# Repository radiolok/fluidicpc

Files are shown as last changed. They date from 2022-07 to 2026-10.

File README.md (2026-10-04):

# FluidicPC

Вычислительные устройства на элементах струйной логики: от моделей отдельных элементов и расчёта течения до синтеза схем и разводки плат.

## Проекты и инструменты

| Папка | Что внутри |
|---|---|
| [`calculator/`](calculator) | **Струйный калькулятор** — арт-объект на 852 элементах: распознаёт символ с матрицы трубочек 5 × 7, считает и показывает результат на семисегментных индикаторах. Модель, структурный и высокоуровневый Verilog, расчёты питания и конструктива |
| [`adder/`](adder) | 4-разрядный сумматор: Verilog, синтез в библиотеку струйных элементов (`fluidic.lib`), тестбенч |
| [`elements/`](elements) | 3D-модели элементов «Волга» (СТ41, СТ42, СТ43, СТ55, СТ56, СТ59, СТ60, СТ63 и др.) во FreeCAD |
| [`bench/`](bench) | расчёт течения в элементе СТ41 в OpenFOAM: подготовка сетки и запуск на кластере |
| [`sch/`](sch) | схемы и плата сумматора в KiCad |
| [`verilog2netlist/`](verilog2netlist) | конвертер синтезированного Verilog в netlist и плату KiCad |

## Струйный калькулятор

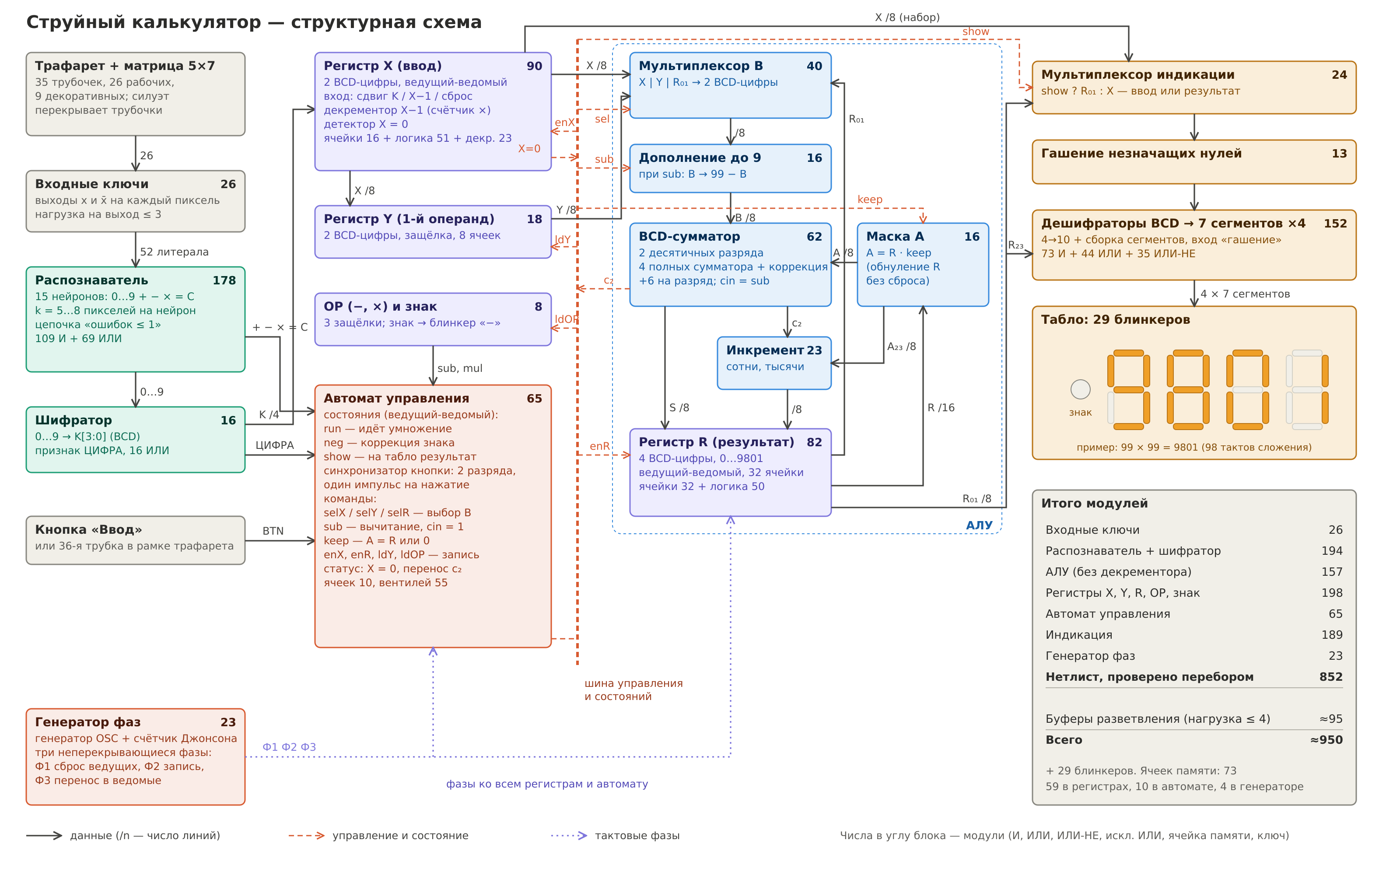
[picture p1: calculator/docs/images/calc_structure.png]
Структурная схема калькулятора


Ввод — трафарет на матрице трубочек и кнопка «Ввод». Операнды от 0 до 99, операции `+ − ×`. Схема разложена на 8 даёв по 150 элементов. Даи попарно собраны в 4 вертикальных блока, блоки стоят на объединительной плите с буферной полостью питания.

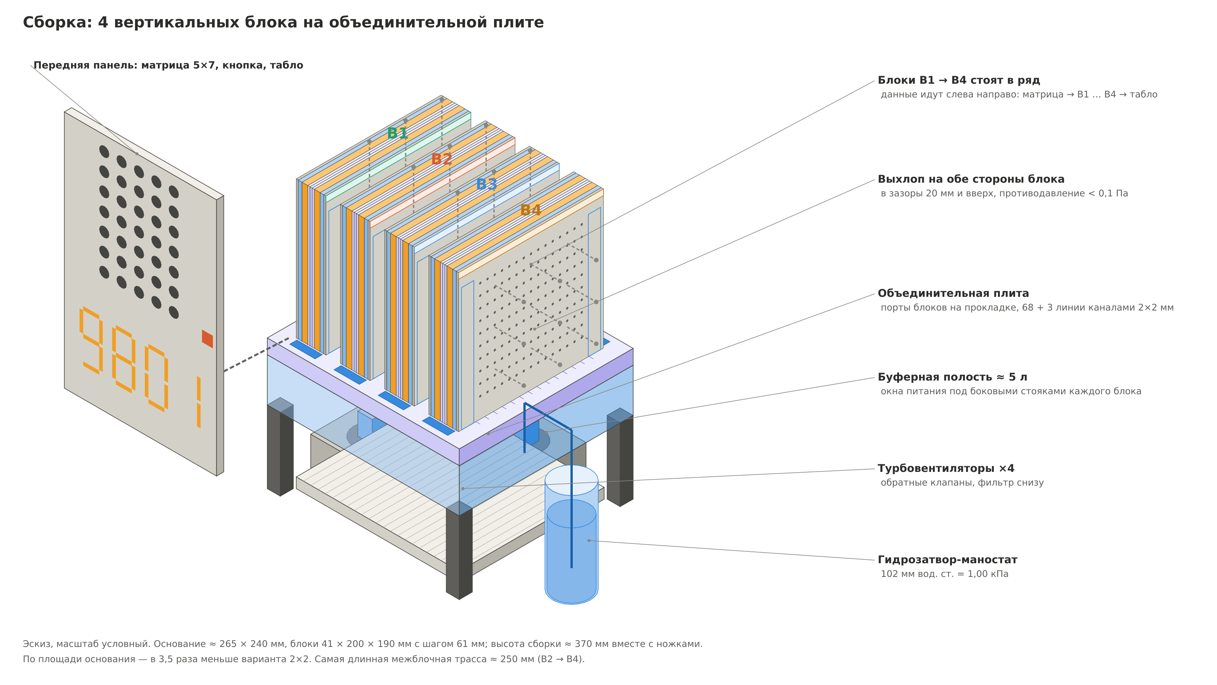
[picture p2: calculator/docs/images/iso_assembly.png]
Сборка: 4 блока на объединительной плите


Подробнее — в [`calculator/README.md`](calculator/README.md).

## Лицензия

[LICENSE](LICENSE)

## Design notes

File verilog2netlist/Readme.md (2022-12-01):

# verilog to netlist
Конвертирует verilog в netlist из которого можно сделать pcb в KiCad 6.

## Установка
Установка зависимостей
```:bash
pip install pipenv
pipenv shell
pipenv install
```
Зависимости: Python 3.8 или выше

## Использование

В папке `FA` содержится пример пустого проекта со всеми библиотеками добавленными в проект. Эти библиотеки используются при создании netlist.

`FA_result` уже готовый что будет после работы скрипты. 

Конфигурационный файл config.py 

Для каждого модуля создаются свои правила по ключу в словаре. Каждый объект правил содержит ключи:
- `verilog_type` — имя в элемента в верилог файле обязательно должны быть элементы для `input` и для `output` остальные например `NOT `опциональны если правила нет элемент в netlist не добавляется
- `kicad_schematic_lib` — имя кикад библиотеки схем так как его назвали при экспортировании в диалоге проекта Kicad 6 `Preferences → Manage Symbol Libraries... → Project Specific Libraries`
- `kicad_scheamtic_element` — Имя элемента как назван в библиотеке схем экспортированной выше
`kicad_footprint` — футпринт элемента в формате `{имя библиотеки}:{имя элемента}` в диалоге проекта Kicad 6 `Preferences → Manage Footprint Libraries... → Project Specific Libraries`
- `pins` — правила замены имен пинов из верилог файла в пины элемента Kicad. Пины в кикад могут быть названия как по `name` так и по `number`. В shematic элемента у пина могут быть указаны как `name` так и `number` оба параметра могут быть текстом. У footprint у пинов есть только `number`

Пример:

```
...
"FA": [{
    "verilog_type": "input",
    "kicad_schematic_lib": "FA",
    "kicad_schematic_element": "HOLE",
    "kicad_footprint": "FA:HOLE",
    "pins": {},
},
    {
    "verilog_type": "output",
        "kicad_schematic_lib": "FA",
        "kicad_schematic_element": "HOLE",
        "kicad_footprint": "FA:HOLE",
        "pins": {},
},{
    "verilog_type": "NOR",
        "kicad_schematic_lib": "FA",
        "kicad_schematic_element": "NOR",
        "kicad_footprint": "FA:NOR",
        "pins": {
            ".A": {
                "number": "4"
            },
            ".B": {
                "number": "5"
            },
            ".Y": {
                "number": "7"
            }},
},]
...
```
Элементы верилог файла
```
...
  input ci;
...
  output co;
...
  NOR _12_ (
    .A(_05_),
    .B(_06_),
    .Y(_08_)
  );
...
```

## Командная строка 
```
> python main.py
```

```
> python main.py --help
usage: main.py [-h] [-i [INPUT]] [-l [LIB]]
               [-o [OUTPUT]]

Convert verilog file to netlist

optional arguments:
  -h, --help            show this help
                        message and exit
  -i [INPUT], --input [INPUT]
                        Input verilog file.
                        default is verilog_in
                        puts/adder_synth.v
  -l [LIB], --lib [LIB]
                        Add kicad library
                        path. Multiple path
                        is allowed. default
                        is FA
  -o [OUTPUT], --output [OUTPUT]
                        Output folder.
                        default is
                        netlists_outputs
```
Необязательные параметры
- `-i` — имя входного верилог файла
- `-l` — путь до библиотеки Kicad 6 можно использовать не только проектную, но и глобальную библиотеку. Пути можно найти в документации по Kicad 6, можно добавить несколько путей для библиотек искать будет во всех.
- `-o` — имя папки куда попадут netlist от каждого модуля. Имя файла будет имя модуля с расширением `*.net`

## Что делать с netlist

Можно создать новый проект добавиь в него все библиотеки из исходного проект `*.kicad_sym`, папки `*.pretty` с файлами с расширением `*.kicad_mod`

В файле проект открыть `PCB editor`

Нажать `File → Import → Netlist` в Диалоге нажать `Update PCB` закрыть `Close`

К курсору прилипнут все элементы из netlist расположить их в удобном месте. Все соединенные пины должны быть соединены прямой линией

Расставить как будет удобно.

После этого можно будет сделать автотрассировку

## Автотрассировка

Скачать и установть LayoutEditor https://layouteditor.com/download если нет java то её тоже установить https://www.java.com/

Нажать в Kicad PCD Editor `File → Export → Spectra DSN...` сохранить.

В установленном приложении LayoutEditor найти файл `freeRouting.jar` в Windows в папке программ `LayoutEditor\bin\freeRouting.jar`

Запустить в диалоге выбрать `*.dsn` файл созданные ранее. 

В открывшемся приложении выборать `Routing → Autorouting` Когда процесс завершится нажать `File → Export → Export Spectra Session File` Файл сохранится в той же папке и с тем же названием только расширение будет `*.ses` на вопрос нажать `Yes`

В `PCB Editor` из Kicad открыв тот же файл куда импортировался netlist нажать `File → Import → Spectra Session...` выбрать новый `*.ses` файл. Все элементы соединятся проводниками.

Теперь можно выбрать один или несколько выходов и нажать апостроф "`" пути соединений будут подсвечены.

Удалить путь чтобы разметить заново `Edit → Global Deletations...` выбрать `Tracks & vias` → `OK` → `Yes`. Теперь можно переставить элементы и разметить заново.

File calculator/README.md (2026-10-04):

# Струйный калькулятор

Вычислительное устройство на элементах струйной логики (прилипание ламинарной струи к стенке), задуманное как арт-объект. Символ задаётся трафаретом: силуэт перекрывает часть трубочек матрицы 5 × 7. Машина распознаёт символ, считает в двоично-десятичном коде и показывает результат на четырёх семисегментных индикаторах из блинкеров. Умножение выполняется повторным сложением по одному такту, поэтому сумма на табло растёт на глазах, как у арифмометра.

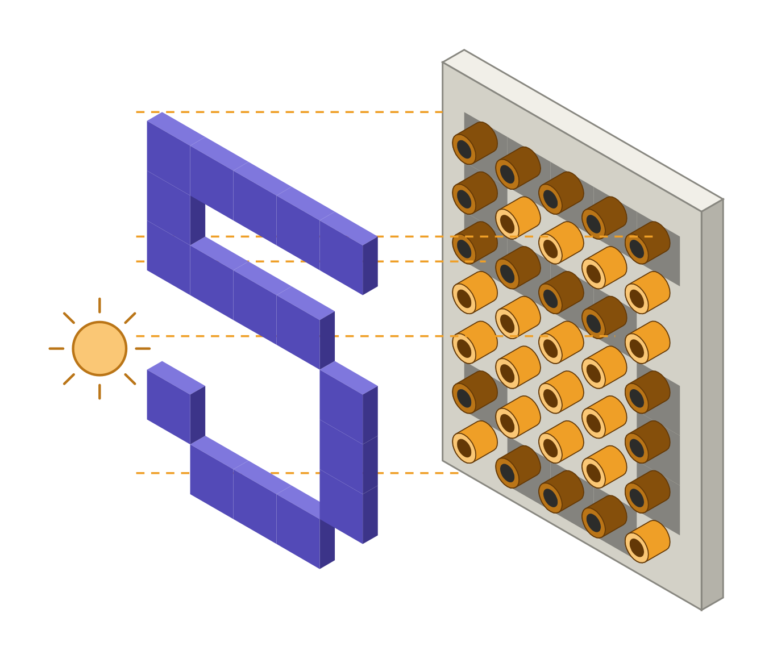
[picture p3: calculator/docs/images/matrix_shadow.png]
Трафарет отбрасывает тень на матрицу трубочек


| Параметр | Значение |
|---|---|
| Ввод | матрица 5 × 7 трубочек (26 рабочих) и кнопка «Ввод» |
| Символы | `0–9 + − × = C`; одна ошибка пикселя не мешает распознаванию |
| Операнды и результат | 0…99, результат −99…9801 |
| Вывод | 4 семисегментных индикатора и блинкер «−» (29 блинкеров) |
| Логика | 852 элемента: 2И, 2ИЛИ, 2ИЛИ-НЕ, НЕ, 2искл.ИЛИ, RS-ячейка, ключ, генератор |
| Конструктив | 8 даёв 15 × 10 мест → 4 вертикальных блока по 2 дая → объединительная плита |
| Питание | ≈ 1 кПа, ≈ 500 л/мин, Re сопла ≈ 1150 |
| Такт | 3 фазы, ≈ 3 Гц; 99 × 99 считается ≈ 35 с |

## Документация

| Раздел | Что внутри |
|---|---|
| [Архитектура](docs/architecture.md) | распознаватель, регистры, порядок работы, АЛУ, тактирование, подсчёт элементов, быстродействие, допущения |
| [Конструктив](docs/construction.md) | место элемента, дай, вертикальный блок, разбиение по даям и блокам, объединительная плита |
| [Питание](docs/power.md) | режим сопла, расход, источник, полости, стояки, выхлоп, бюджет давления |

Структурная схема калькулятора

## Структура папки

| Папка | Содержимое |
|---|---|
| [`model/`](model) | эталонная модель на Python: вентильный нетлист, симулятор, тесты, генераторы Verilog. Источник правды для всего остального |
| [`netlist/`](netlist) | структурный Verilog для разводки: 8 даёв, 4 блока, верхний уровень, библиотека ячеек, тестбенчи. **Генерируется** из `model/`, руками не править |
| [`rtl/`](rtl) | высокоуровневая (поведенческая) модель на Verilog и её тестбенч |
| [`calc/`](calc) | отдельные расчёты: подбор весов распознавателя, пневматика, разбиение по даям |
| [`docs/`](docs) | описание проекта; картинки в `docs/images/`, скрипты, которые их рисуют, — в `docs/src/` |
| [`ci/`](ci) | обвязка шагов CI |

## Две версии на Verilog

**Структурный нетлист** (`netlist/`) — то, что идёт в разводку. Каждый экземпляр ячейки — один физический элемент на плате. Иерархия повторяет конструктив: модуль дая, модуль блока из двух даёв, верхний уровень с линиями объединительной платы.

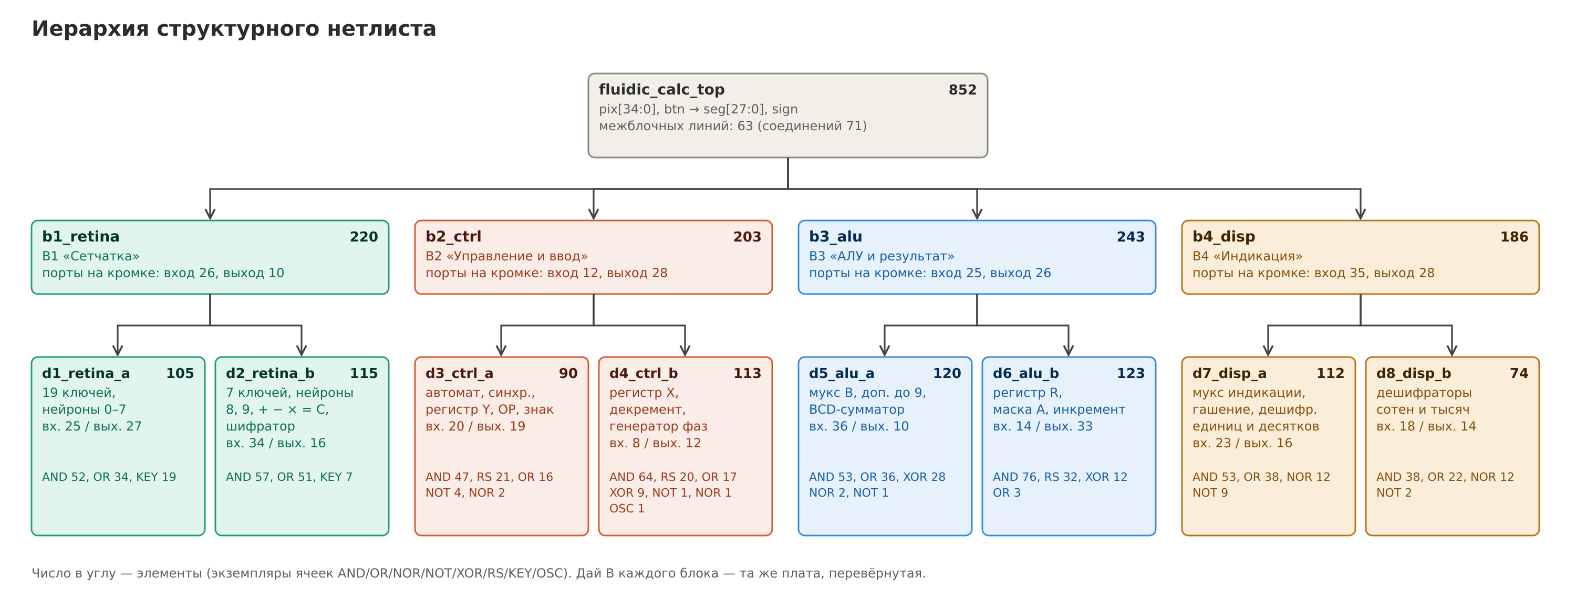
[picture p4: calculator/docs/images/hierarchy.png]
Иерархия структурного нетлиста


| Порт верхнего уровня | Назначение |
|---|---|
| `pix[34:0]` | трубочки матрицы, `pix[r*5 + c]`: r = 0…6 строка сверху, c = 0…4 столбец слева; 1 — трубочка закрыта |
| `btn` | кнопка «Ввод» |
| `seg[27:0]` | сегменты, `seg[7*k + j]`: k = 0 единицы … 3 тысячи; j = 0…6 сегменты a…g |
| `sign` | блинкер «−» |

Библиотека ячеек [`netlist/cells/fluidic_cells.v`](netlist/cells/fluidic_cells.v) с макросом `SYNTHESIS` превращает элементы в чёрные ящики, и иерархия даёв и блоков сохраняется при синтезе. Без макроса это поведенческие модели с задержкой элемента. Для yosys есть Liberty-описание [`netlist/cells/fluidic_calc.lib`](netlist/cells/fluidic_calc.lib).

**Высокоуровневая модель** ([`rtl/fluidic_calc_rtl.v`](rtl/fluidic_calc_rtl.v)) описывает те же регистры, события и уравнения арифметикой, без вентилей. Один фронт `clk` в ней соответствует одному такту машины. Она служит эталоном: тестбенч `netlist/tb_cosim.v` гоняет её одновременно с нетлистом и сверяет табло после каждого такта.

## Как проверить

Нужны `python3`, `iverilog` и `yosys`.

```sh
cd calculator
make model     # тесты Python-модели, структурная проверка нетлиста, сверка с RTL-зеркалом
make rtl       # тестбенч высокоуровневой модели
make netlist   # тестбенч структурного нетлиста с настоящим генератором фаз
make cosim     # нетлист и высокоуровневая модель такт в такт
make stat      # подсчёт элементов по даям и блокам
make regen     # перегенерировать нетлист и тестбенчи из модели
```

Все шаги запускает CI ([`.github/workflows/calculator.yml`](../.github/workflows/calculator.yml)). Он же проверяет, что закоммиченный нетлист совпадает с тем, что генерирует модель.

Полный перебор всех примеров `a op b` для a, b = 0…99 и `+ − ×` (30 000 штук) запускается отдельно, `python3 model/test_model.py full`, и идёт около часа. На текущей модели он проходит без ошибок.

## Перенос в KiCad

Нетлист даёв можно передать конвертеру [`verilog2netlist`](../verilog2netlist). В [`config.py`](../verilog2netlist/config.py) для даёв описаны правила только для NOR, OR и NOT: это элемент `FA:NOR`, ИЛИ снимается с вывода 6, ИЛИ-НЕ — с вывода 7. Для AND, XOR, RS-ячейки, ключа трубочки и генератора символов и футпринтов пока нет. Без правила элемент в netlist не попадает, поэтому правила нужно дописать, когда появятся библиотеки.

## Что ещё не сделано

- Буферы разветвления (≈ 95 при нагрузке на выход до 4) в нетлист не вставлены. Их удобнее добавлять при разводке, когда известны коэффициент разветвления и длины каналов.
- Сброса по включению нет: после подачи давления машина может минуту досчитывать случайное «умножение».
- Задержка элемента (1,5 мс), расход входа управления и допустимая нагрузка на выход — оценки. Их нужно измерить на реальных элементах. Что от них зависит — в разделе «Допущения» [архитектуры](docs/architecture.md#допущения).

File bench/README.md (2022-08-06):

## Openfoam preparations:

Install openfoam on Linux, or WSL [full instruction](https://develop.openfoam.com/Development/openfoam/-/wikis/precompiled/debian)

```bash
# Add the repository
curl https://dl.openfoam.com/add-debian-repo.sh | sudo bash

# Install preferred package. Eg,
sudo apt-get install openfoam2206-default

# Use the openfoam shell session. Eg,
openfoam2206
```

## ST41 openmpi benchmark

1. init env variables. Your openFoam installation might be differen

```bash

source /opt/OpenFoam_v2206/etc/bashrc
```

2. Prepare repo data

```bash
git clone https://github.com/radiolok/fluidicpc
cd fluidicpc/bench/st41_50u/meshCase
./Allmesh # run mesh preparation
cd ../case/
```

3. Prepare data for openMPI - set slots=CPUnum in your system

```bash
vim hostfile

127.0.0.1 slots=16
```

4. Set number of threads for current run

```bash
vim system/decomposeParDict

numberOfSubdomains  16;// <= change value in this line

```

5. Run simulation fo 50 iterations:

```bash
./Allrun
```

6. 

```bash
Time = 50

smoothSolver:  Solving for Ux, Initial residual = 0.016608048, Final residual = 0.0014078031, No Iterations 1
smoothSolver:  Solving for Uy, Initial residual = 0.0078743367, Final residual = 0.00052424984, No Iterations 1
smoothSolver:  Solving for Uz, Initial residual = 0.062228509, Final residual = 0.0056502976, No Iterations 1
GAMG:  Solving for p, Initial residual = 0.074983923, Final residual = 0.00061506252, No Iterations 3
GAMG:  Solving for p, Initial residual = 0.001528043, Final residual = 9.3656366e-06, No Iterations 12
GAMG:  Solving for p, Initial residual = 0.00021100964, Final residual = 1.4637146e-06, No Iterations 7
GAMG:  Solving for p, Initial residual = 3.1508808e-05, Final residual = 2.0603363e-07, No Iterations 7
GAMG:  Solving for p, Initial residual = 7.9916881e-06, Final residual = 6.9259462e-08, No Iterations 4
GAMG:  Solving for p, Initial residual = 2.0248575e-06, Final residual = 1.8799949e-08, No Iterations 4
time step continuity errors : sum local = 0.00031827139, global = 4.4203807e-06, cumulative = -0.0019786412
smoothSolver:  Solving for omega, Initial residual = 0.0088505726, Final residual = 0.00054960281, No Iterations 3
smoothSolver:  Solving for k, Initial residual = 0.034761292, Final residual = 0.0020115187, No Iterations 3
ExecutionTime = 699.06 s  ClockTime = 699 s <<<=== 699s for current test

End

Finalising parallel run

```

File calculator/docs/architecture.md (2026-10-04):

# Архитектура калькулятора

Структурная схема

## Ввод и распознавание

Символ задаётся трафаретом: силуэт перекрывает часть трубочек матрицы 5 × 7, и ключ каждой трубочки выдаёт прямой и инверсный сигнал. Распознаются 15 символов: `0–9 + − × = C`.

Каждый символ распознаёт свой нейрон с троичными весами: +1 — трубочка должна быть закрыта, −1 — открыта, 0 — нейрон на неё не смотрит. Нейрон срабатывает, если среди его пикселей не совпал с образцом **максимум один**. Веса подобраны перебором ([`calc/recognizer_weights.py`](../calc/recognizer_weights.py)):

- любой другой символ отличается от своего образца минимум в 3 пикселях из набора нейрона, поэтому одна ошибка пикселя не вызывает ни пропуска, ни ложного срабатывания;
- пустая и полностью закрытая матрица не будят ни один нейрон;
- используются 26 трубочек из 35, нагрузка на выход ключа не больше 3.

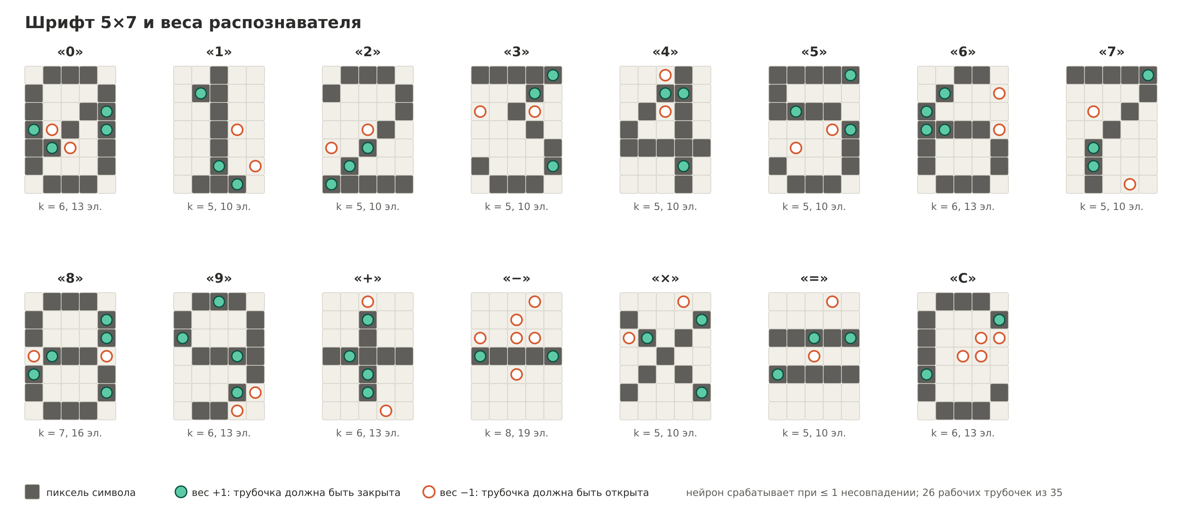
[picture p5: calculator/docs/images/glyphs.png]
Шрифт и веса


«Не более одного несовпадения» — это цепочка из двух рельсов на 2И/2ИЛИ, 3k − 5 элементов на нейрон из k пикселей:

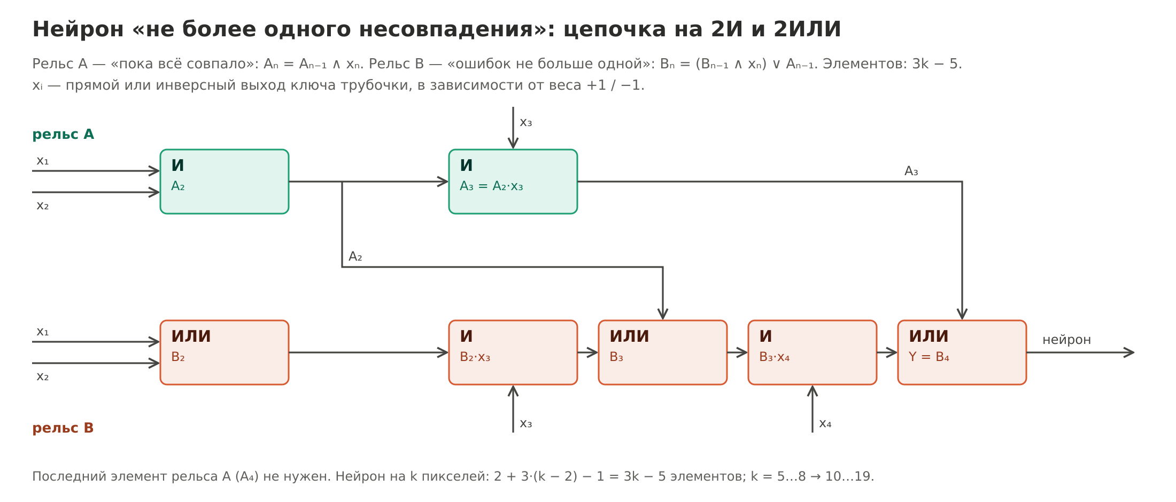
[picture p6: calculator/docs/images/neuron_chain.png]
Нейрон-цепочка


Шифратор собирает 10 выходов цифр в BCD-код K[3:0] и признак «цифра» — 16 элементов ИЛИ.

## Регистры и порядок работы

| Регистр | Разрядность | Тип | Назначение |
|---|---|---|---|
| X | 2 BCD-цифры | ведущий-ведомый | набираемое число; счётчик при умножении |
| Y | 2 BCD-цифры | защёлка | первый операнд |
| R | 4 BCD-цифры | ведущий-ведомый | результат, аккумулятор |
| OP | 2 бита | защёлка | отложенная операция: вычитание, умножение |
| знак | 1 бит | защёлка | блинкер «−» |
| run, neg, show | 3 бита | ведущий-ведомый | состояния автомата |
| синхронизатор | 2 бита | ведущий-ведомый | один импульс на нажатие кнопки |

| Нажатие | Действие |
|---|---|
| цифра | X ← X·10 + цифра (две последние). После показа результата начинает новый пример |
| `+ − ×` | Y ← X, OP ← операция, R ← X (для `×` R ← 0), X ← 0 |
| `=` при `+` | R ← R + X — 1 такт |
| `=` при `−` | R ← R + (99 − X) + 1; если переноса нет (результат отрицательный) — ещё такт: R ← (99 − R) + 1, знак ← 1 |
| `=` при `×` | пока X ≠ 0: R ← R + Y, X ← X − 1 — по такту на сложение, табло показывает растущую сумму |
| `C` | сброс X, R, OP и знака |

Во время умножения и коррекции знака кнопки игнорируются. `+ − × =` после показа результата тоже игнорируются: новый пример начинается с цифры или `C`.

АЛУ — двухразрядный BCD-сумматор (4 полных сумматора и коррекция +6 на разряд), перед ним мультиплексор операнда B (X, Y или R₀₁) и дополнение до 9 при вычитании; сотни и тысячи только инкрементируются переносом. Индикация показывает X при наборе и R после `=`, незначащие нули гасятся.

## Тактирование

Данные в схеме идут без инверсии, поэтому ведущая ячейка пишется в два шага, а перенос в ведомую идёт по обоим выходам ведущей — без провала в ноль, табло не мигает на каждом такте:

| Фаза | Действие |
|---|---|
| Ф1 | сброс ведущих ячеек регистров с разрешённой записью: `R = Ф1·en` |
| Ф2 | установка ведущих по данным: `S = D·Ф2·en` |
| Ф3 | перенос в ведомые: `S = M·Ф3`, `R = M̄·Ф3` |

Фазы даёт генератор на дае D4: струйный генератор OSC, два буфера задержки, разрешения ведущих и ведомых ячеек без перекрытия и двухразрядный счётчик Джонсона. Такт машины — 4 периода OSC.

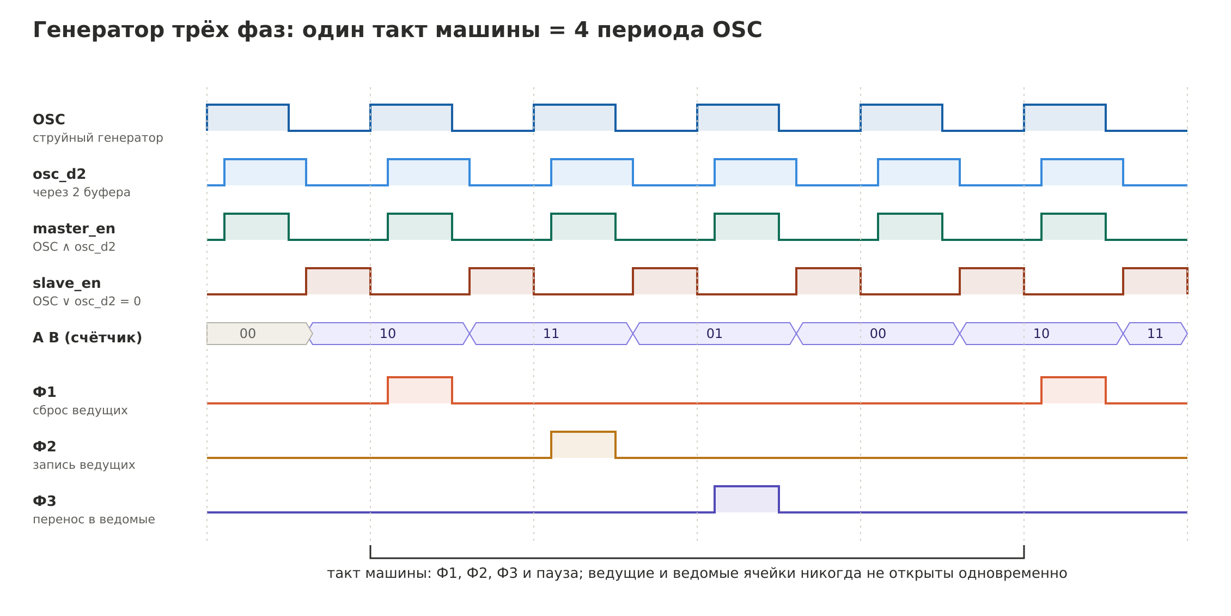
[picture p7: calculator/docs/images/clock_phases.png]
Фазы


## Элементы

| Узел | Элементов |
|---|---|
| Входные ключи | 26 |
| Распознаватель (15 нейронов) | 178 |
| Шифратор | 16 |
| Мультиплексор B | 40 |
| Дополнение до 9 | 16 |
| Маска A | 16 |
| BCD-сумматор, 2 разряда | 62 |
| Инкремент сотен и тысяч | 23 |
| Регистр X (16 ячеек + 51) + декремент и X = 0 (23) | 90 |
| Регистр R (32 ячейки + 50) | 82 |
| Регистр Y (8 ячеек + 10) | 18 |
| OP и знак (3 ячейки + 5) | 8 |
| Автомат управления (10 ячеек + 55) | 65 |
| Мультиплексор индикации | 24 |
| Гашение незначащих нулей | 13 |
| Дешифраторы 7-сегм. ×4 | 152 |
| Генератор фаз (OSC + 4 ячейки + 18) | 23 |
| **Итого** | **852** |

По ячейкам: AND 440, OR 217, NOR 29, NOT 17, XOR 49, RS 73, KEY 26, OSC 1. Буферы разветвления (≈ 95 при нагрузке на выход до 4) в нетлист не вставлены — это физическая доработка под реальный коэффициент разветвления элементов.

## Быстродействие

Самый длинный комбинационный путь — 50 элементов. При ≈ 1,5 мс на элемент вместе с каналом фаза должна длиться 80–100 мс, такт — 0,3–0,4 с (≈ 3 Гц). Сложение и вычитание занимают 1–2 такта, умножение 99 × 99 — 98 тактов, около 35 с. Время на элемент — оценка, его нужно измерить.

## Допущения

| Допущение | Что будет, если неверно |
|---|---|
| Ячейка памяти даёт Q и Q̄ | +51 инвертор |
| Нагрузка на выход — до 4 входов | при 3 — ≈ +95 буферов, бюджет 1000 превышен |
| Расход входа управления 0,1–0,2 л/мин | каналы плиты и соединительного пакета должны быть шире |
| ≈ 1,5 мс на элемент | такт медленнее или быстрее |
| Сброса по включению нет | после включения машина может досчитать «умножение» до 35 с |

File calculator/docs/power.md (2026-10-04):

# Питание

Все числа этого раздела считает [`calc/pneumatics.py`](../calc/pneumatics.py) — при изменении размеров достаточно поправить константы в начале скрипта.

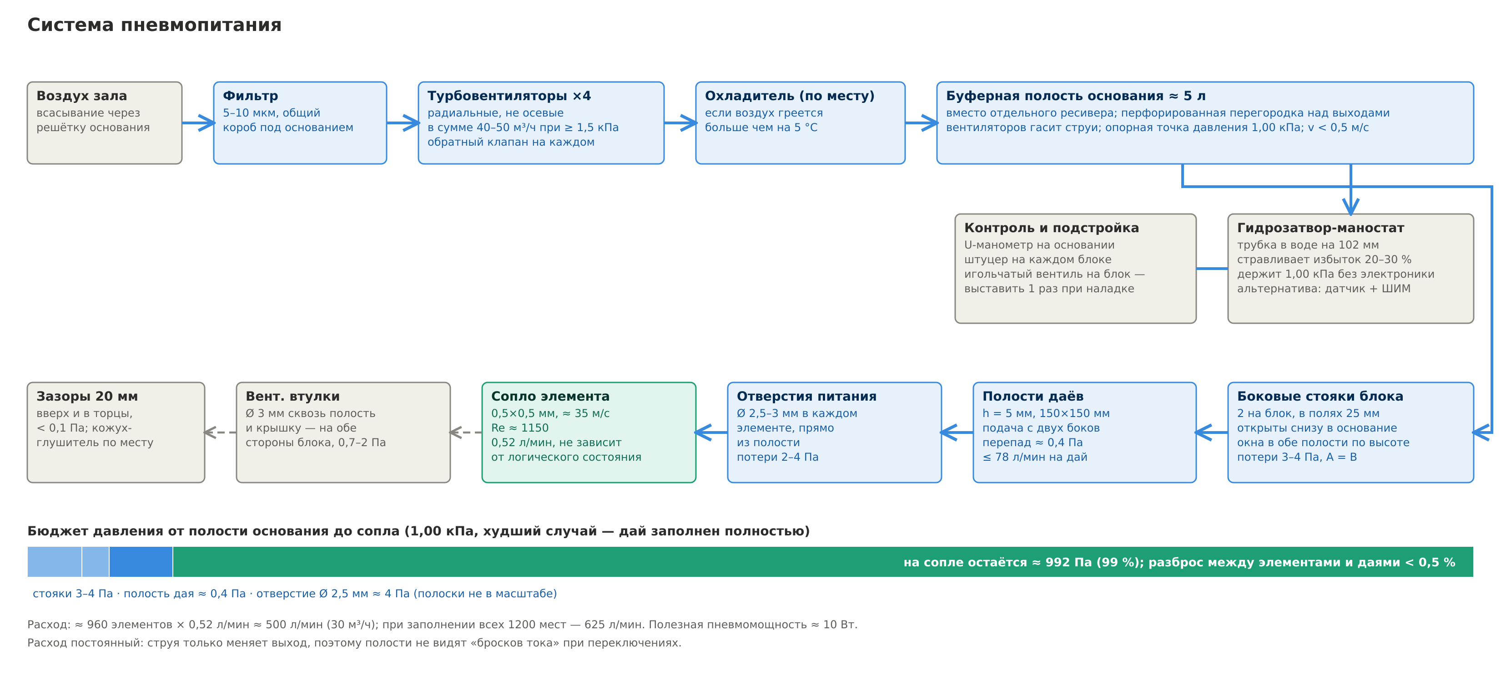
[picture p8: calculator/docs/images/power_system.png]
Система пневмопитания


## Режим сопла

Сопло 0,5 × 0,5 мм (гидравлический диаметр 0,5 мм), воздух 20 °C, ν = 1,5·10⁻⁵ м²/с, коэффициент расхода 0,85; v = Cd·√(2p/ρ).

| Давление | Скорость струи | Re | Расход на элемент |
|---|---|---|---|
| 0,50 кПа | 24 м/с | 810 | 0,37 л/мин |
| 0,75 кПа | 30 м/с | 1000 | 0,45 л/мин |
| **1,00 кПа** | **35 м/с** | **1150** | **0,52 л/мин** |
| 1,50 кПа | 42 м/с | 1410 | 0,64 л/мин |
| 2,00 кПа | 49 м/с | 1630 | 0,74 л/мин |

Рабочее окно — Re ≈ 800–1200: выше свободная струя теряет ламинарность, ниже прилипание вялое и растёт время переключения. Номинал — **1,0 кПа**. Для сравнения, у СМСТ-2 рабочее давление 0,01–0,02 кгс/см², то есть 1–2 кПа.

Главное свойство для питания: **расход элемента не зависит от его логического состояния** — струя только меняет выход. Полости не видят бросков нагрузки при переключениях, в отличие от шины питания КМОП.

## Расход

| Что питаем | Расход |
|---|---|
| Один дай, 150 мест | 78 л/мин |
| Один блок, 300 мест | 156 л/мин |
| Вся машина, ≈ 950 элементов с буферами | ≈ 500 л/мин (30 м³/ч) |
| Все 1200 мест | 625 л/мин (37,5 м³/ч) |

Полезная пневмомощность ≈ 10 Вт; электрическая мощность вентиляторов с учётом КПД — порядка 40–60 Вт.

## Источник воздуха

- **Турбовентиляторы ×4** под основанием — только радиальные: осевой вентилятор развивает лишь сотню-другую паскалей. Рабочая точка каждого по его характеристике P–Q — около 1,3–1,5 кПа при четверти общего расхода (≈ 150 л/мин), в сумме 40–50 м³/ч с запасом на сброс.
- **Обратный клапан на каждом**, иначе остановившийся вентилятор становится утечкой.
- **Фильтр 5–10 мкм** на общем всасывании. Сетка нужна и на трубочках матрицы: они всасывают воздух зала вместе с пылью.
- **Охлаждение по месту.** При нагреве на 10 °C кинематическая вязкость воздуха растёт примерно на 6 %, и Re при том же давлении падает на столько же. Если воздух греется больше чем на 5 °C — радиатор или несколько метров шланга.

### Вариант: мотор пылесоса

Подходит, но только со сниженными оборотами. Типовой мотор на 1–1,5 кВт даёт 20–30 кПа и 40–50 л/с; на полных оборотах почти весь воздух пришлось бы стравливать. По законам подобия (давление ∝ n², расход ∝ n, мощность ∝ n³) точка 11 л/с при 1,5 кПа получается примерно на **40 % оборотов** и **60–80 Вт** мощности.

- Обороты — фазовым регулятором (коллекторный мотор) или ШИМ; точное давление держит маностат.
- **Только байпасный мотор** с отдельным охлаждением: в проточном рабочий воздух уносит угольную пыль щёток прямо в сопла 0,5 мм. Ещё лучше бесщёточный мотор от аккумуляторного пылесоса.
- Ресурс щёток коллекторного мотора — сотни часов; для выставки это повод держать запасной.

## Буферная полость основания

- Объём ≈ 4–5 л (≈ 265 × 240 × 60–80 мм) гасит пульсации вентиляторов; отдельный ресивер не нужен.
- Скорость в полости меньше 0,5 м/с — это **опорная точка давления** для всей машины.
- **Перфорированная перегородка** над выходами вентиляторов обязательна: струя турбовентилятора несёт динамическое давление в десятки паскалей, и без перегородки ближайшие стояки получат завышенное давление.
- Окна питания в плите — только под боковыми стояками блоков, по краям. Середина плиты свободна для сигнальных каналов, поэтому питание и сигналы не пересекаются.
- **Гидрозатвор-маностат**: трубка из полости, опущенная в воду на **102 мм**. Вентиляторы подают на 20–30 % больше, чем нужно, избыток уходит пузырями, и давление получается ровно 1,00 кПа независимо от сети, нагрева и засорения фильтра. Воду нужно доливать; пузыри в стеклянной банке — часть арт-объекта. Электронная альтернатива — датчик давления и ШИМ вентиляторов.

## Подача в блок: боковые стояки

Через нижнюю кромку блока воздух подавать нельзя: щель вдоль всей кромки перегородила бы сигнальные каналы плиты под блоком. Поэтому воздух поднимается по двум вертикальным стоякам в боковых полях блока (вырезы во всех слоях, ≈ 17 × 35 мм) и входит в обе полости через окна по всей высоте.

| Параметр | Значение |
|---|---|
| Расход на стояк | ≈ 78 л/мин (по половине двух даёв) |
| Скорость в стояке | ≈ 2,2 м/с, динамический напор ≈ 3 Па |
| Потери на входе и неравномерность по высоте | ≈ 4 Па |
| Даи A и B | питаются из одних стояков симметрично |

## Полость дая

Ламинарное течение в щели высотой h с равномерным отбором; вентиляционные втулки занимают часть сечения (+20 % к сопротивлению).

| h | Подача с одного бока | С двух боков (стояки) |
|---|---|---|
| 4 мм | 2,7 Па | 0,7 Па |
| **5 мм** | 1,4 Па | **0,34 Па** |
| 6 мм | 0,8 Па | 0,2 Па |

Перепад растёт как 1/h³, поэтому экономить на высоте полости нельзя. Втулки стоят рядами вдоль строк элементов, а воздух от боковых стояков идёт как раз вдоль строк, по свободным коридорам; заодно втулки держат крышку полости.

## Отверстие питания элемента

Площадь отверстия из полости к соплу должна быть хотя бы в 10 раз больше площади сопла, иначе разброс сверловки превращается в разброс давлений.

| Отверстие, длина 3 мм | Площадь / площадь сопла | Потери |
|---|---|---|
| 1,0 мм | 3× | 129 Па (13 %) |
| 1,5 мм | 7× | 26 Па |
| 2,0 мм | 13× | 8 Па |
| **2,5–3,0 мм** | **20–28×** | **1,6–3,3 Па** |

## Выхлоп

У элемента два вентиляционных окна — по одному сбоку от каждого выхода. Каждое выводится своей втулкой сквозь полость питания и крышку на наружную сторону блока.

Расход между окнами делится несимметрично: через окно у активного выхода уходит почти весь поток струи, а окно у пассивного выхода может даже подсасывать воздух снаружи. Поэтому каждая втулка считается на полный расход элемента.

| Втулка, длина 8 мм | Противодавление |
|---|---|
| Ø 2,5 мм | ≈ 4 Па |
| Ø 3,0 мм | ≈ 2 Па |
| **Ø 3,5 мм** | **≈ 1,1 Па** |
| Ø 4,0 мм | ≈ 0,6 Па |

- Если окна стоят у краёв места элемента, окна соседних элементов в строке оказываются в 3–4 мм друг от друга; втулки там тонкостенные или овальные. Можно вывести окна двух соседей в одну общую втулку — давление в ней около 1 Па, связь между элементами пренебрежима.
- **Симметрия важнее размера**: обе втулки элемента должны иметь одинаковое сопротивление, иначе пороги переключения смещаются в одну сторону.
- В каждый зазор 20 мм между блоками дуют две стороны соседних блоков (≈ 156 л/мин); воздух уходит вверх и в торцы со скоростью ≈ 0,2 м/с, противодавление меньше 0,1 Па. Для шума ряд можно накрыть кожухом с глушителем сверху.

## Бюджет давления

| Участок | Потери |
|---|---|
| Буферная полость основания | < 0,1 Па |
| Боковой стояк | ≈ 4 Па |
| Полость дая, h = 5 мм, подача с двух боков | ≈ 0,3 Па |
| Отверстие Ø 2,5 мм | ≈ 3 Па |
| **На сопле** | **≈ 992 Па из 1000** |

Важно не абсолютное давление, а согласование: выходное давление элемента пропорционально его питанию, и дай с заниженным питанием слабее управляет соседним. Ориентир — **±3–5 % между даями**, расчётный разброс меньше 0,5 %. Расход постоянный, поэтому достаточно один раз при наладке проверить давление на каждом блоке U-манометром и при необходимости поджать дросселем в окне стояка.

## Пуск и останов

- При подаче давления ячейки памяти встают в случайное состояние. Если случайно окажется установлен `run`, машина досчитает умножение до X = 0 и остановится — до ≈ 35 с, кнопки в это время игнорируются. Сброс по включению (пневматическая задержка: объём + дроссель, которая первую секунду держит входы R ячеек состояния) обойдётся в 2–3 элемента; в нетлисте его пока нет.
- Генератор фаз — двухразрядный счётчик Джонсона: все 4 состояния рабочие, после включения он не зависает.
- Вентиляторы включать одновременно; маностат начинает стравливать, когда давление дошло до 1,00 кПа.

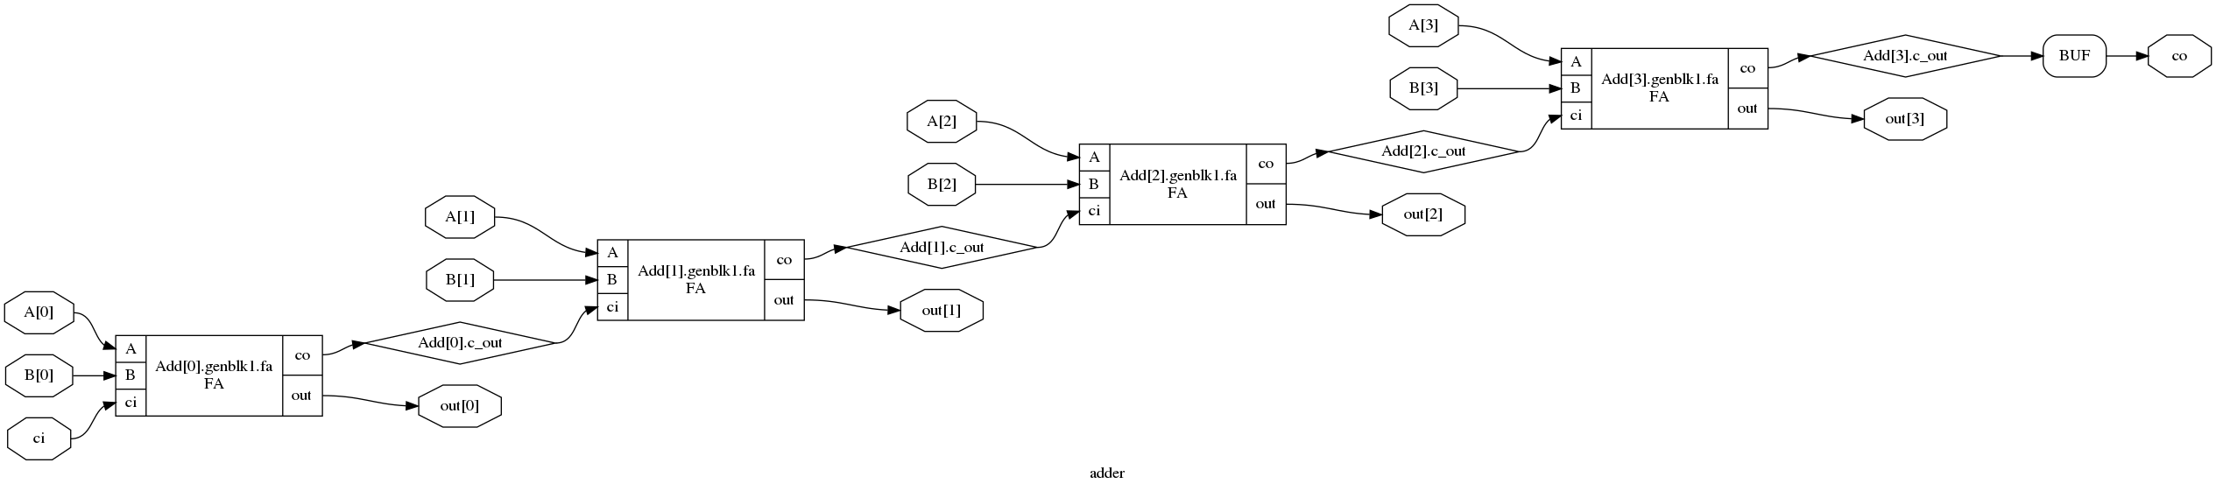
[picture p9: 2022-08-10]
adder/adder.dot.png

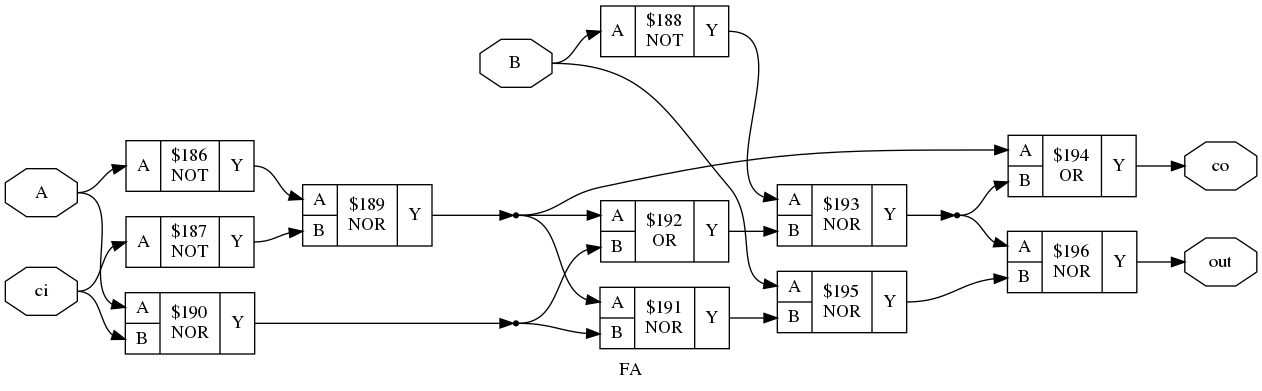
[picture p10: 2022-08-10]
adder/FA.dot.png

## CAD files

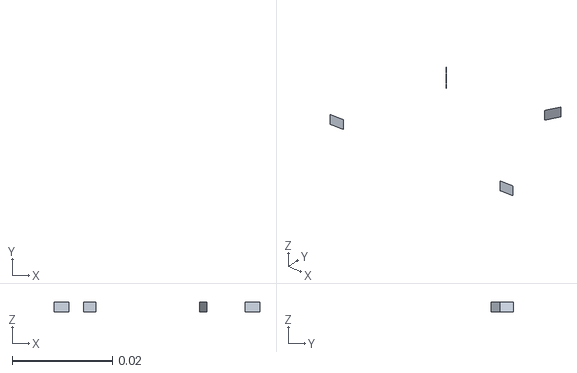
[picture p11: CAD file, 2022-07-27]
bench/st41_50u/meshCase/constant/triSurface/patch_3_0.stl
0.041 x 0.0271 x 0.002

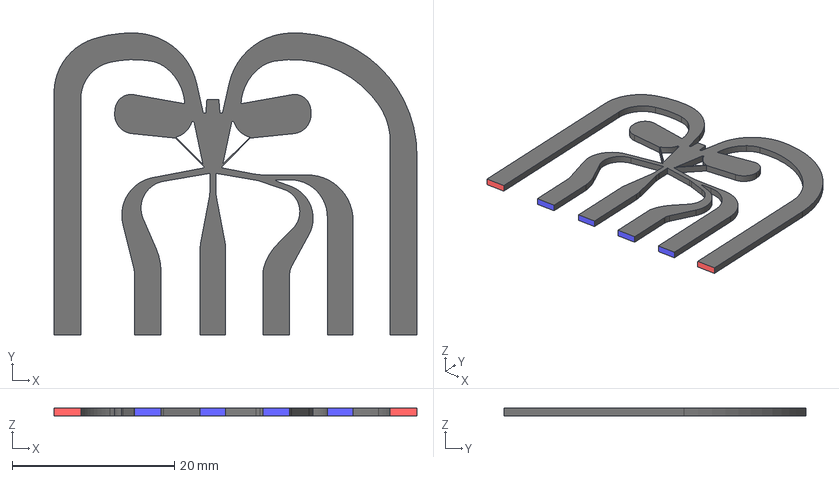
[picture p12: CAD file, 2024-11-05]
elements/ST42.FCStd
44.8 x 37.2 x 1.01 mm
Деталь
wall
Y4
Y5
inlet
X2
X3
X6
open

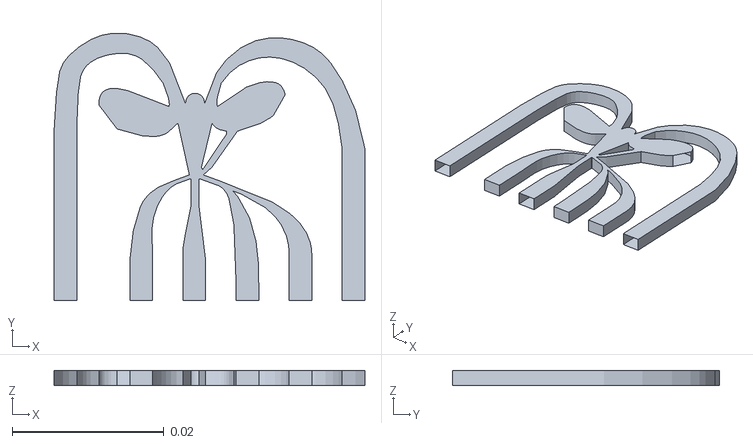
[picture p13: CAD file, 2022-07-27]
bench/st41_50u/meshCase/constant/triSurface/patch_1_0.stl
0.041 x 0.0352 x 0.002

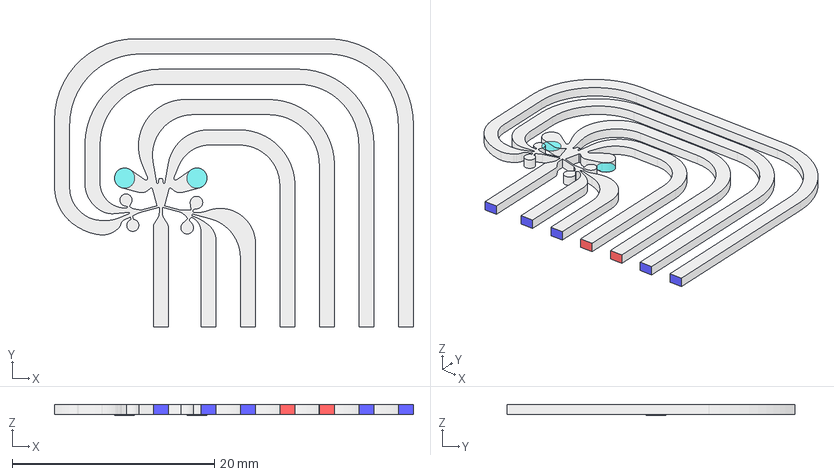
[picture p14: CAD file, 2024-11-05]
elements/ST56.FCStd
35.5 x 28.5 x 1.10 mm
Деталь
inlet
X2
X3
X6
X7
Y4
Y5
open

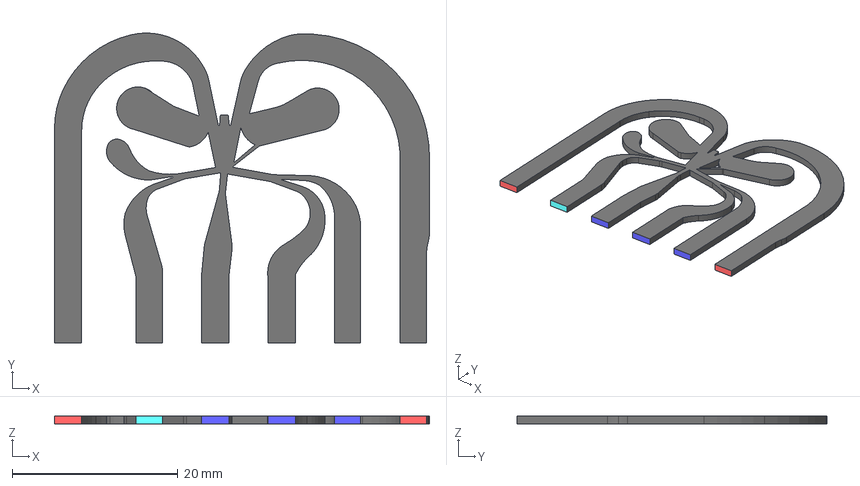
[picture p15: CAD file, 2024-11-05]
elements/ST41.FCStd
45.3 x 37.4 x 1.01 mm
inlet
inlet_X2
inlet_X3
outlet_Y4
outlet_Y5
open
wall

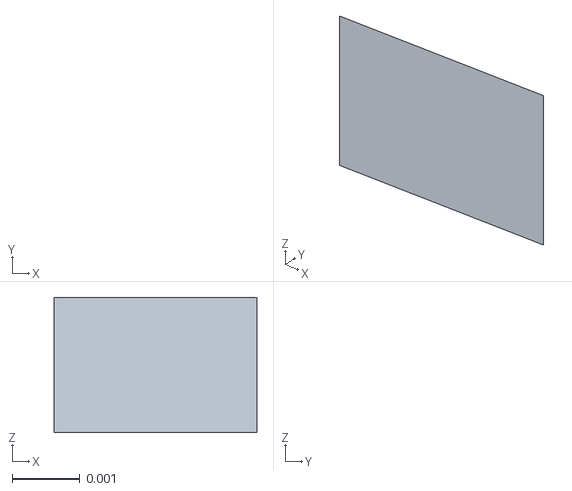
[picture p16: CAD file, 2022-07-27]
bench/st41_50u/meshCase/constant/triSurface/patch_2_0.stl
0.003 x 0 x 0.002

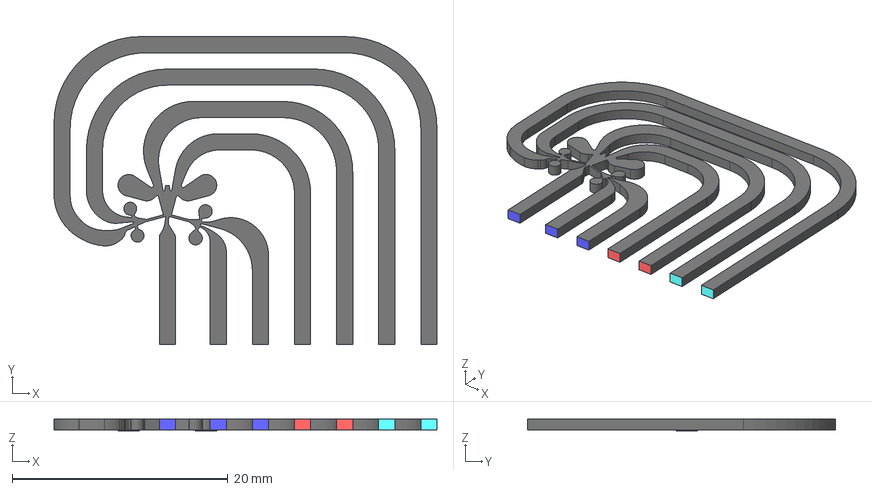
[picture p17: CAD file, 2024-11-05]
elements/ST55.FCStd
35.5 x 28.5 x 1.10 mm
inlet
X2
X3
Y4
Y5
X6
X7
open
wall

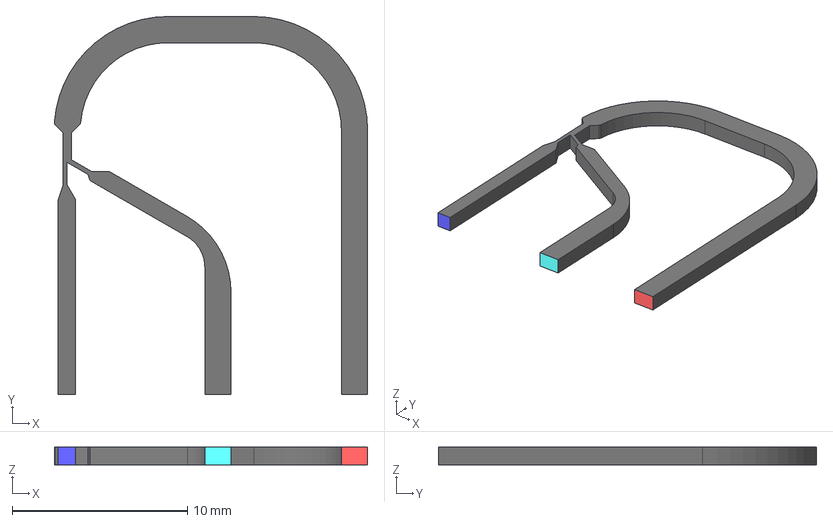
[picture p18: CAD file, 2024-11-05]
elements/ST63.FCStd
17.9 x 21.6 x 1.00 mm
inlet
open
outlet
wall

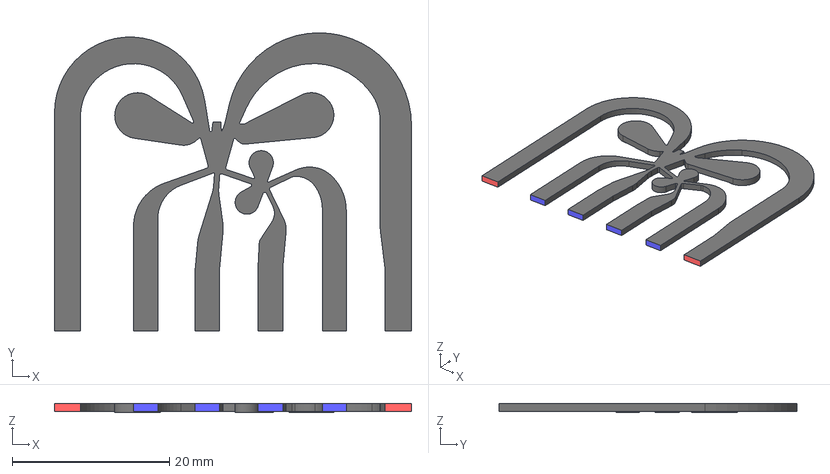
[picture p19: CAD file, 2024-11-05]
elements/ST43.FCStd
45.5 x 38.0 x 1.10 mm
Деталь
inlet
X2
X3
X6
Y4
Y5
open
wall

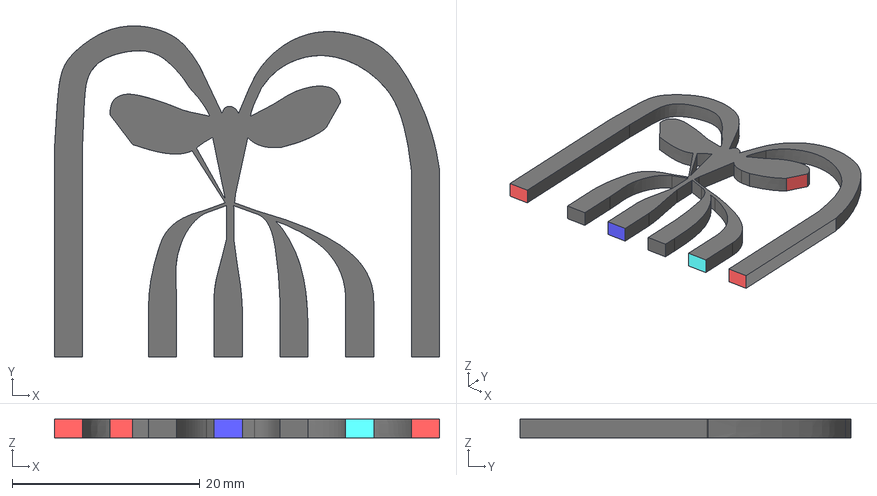
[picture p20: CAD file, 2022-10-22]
elements/CT41_inv.FCStd
41.0 x 35.2 x 2.00 mm
wall
inlet
outlet
inlet001

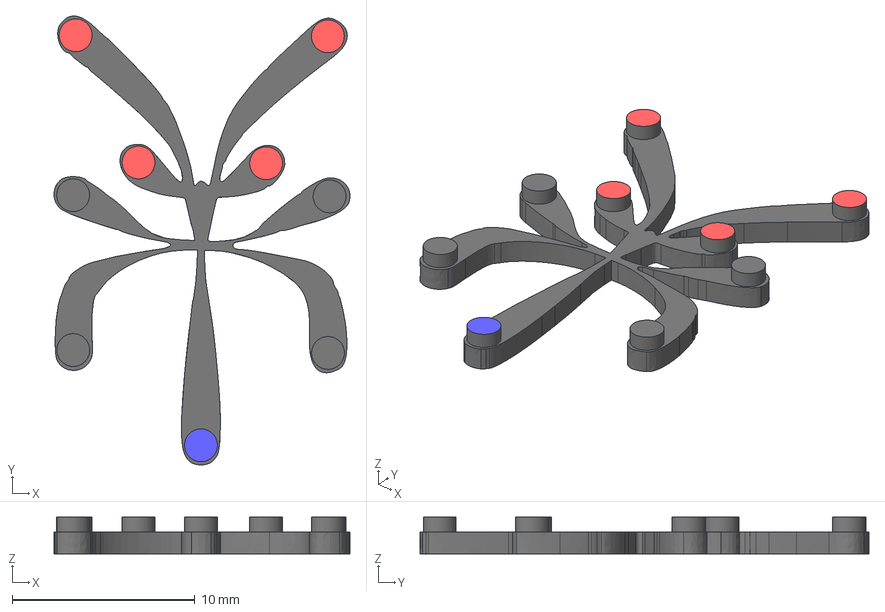
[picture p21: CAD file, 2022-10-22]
elements/frexten.FCStd
16.2 x 24.6 x 2.00 mm
path1527002
inlet
outlet
wall

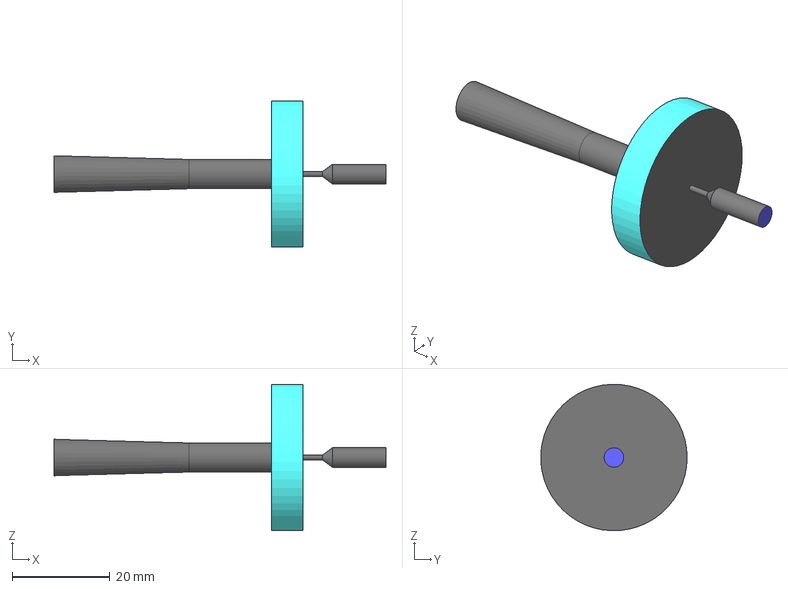
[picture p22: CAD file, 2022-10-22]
elements/Ejector.FCStd
68.0 x 30.0 x 30.0 mm
wall
inlet
outlet
open

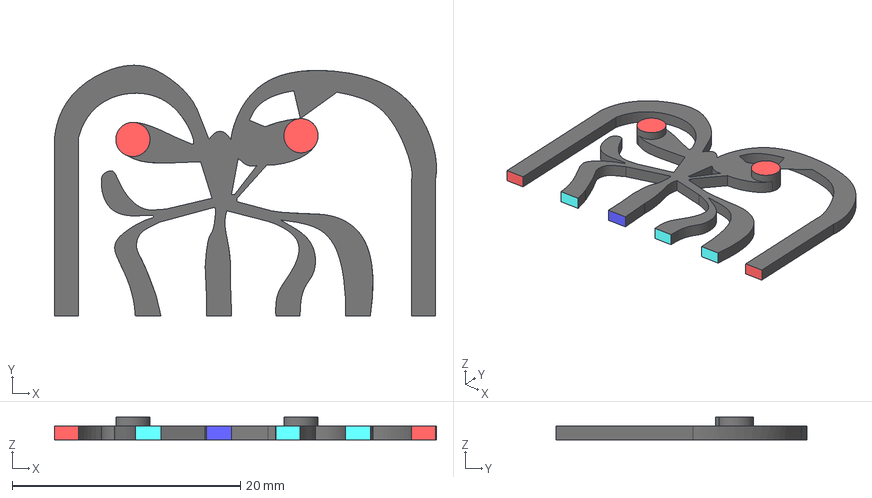
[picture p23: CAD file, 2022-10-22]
elements/CT41_first.FCStd
33.5 x 22.0 x 2.00 mm
st41_bottom
inlet
outlet
open
wall

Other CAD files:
bench/st41_50u/meshCase/constant/triSurface/Pad_Geometry.stl
elements/ST59.FCStd
elements/ST60.FCStd

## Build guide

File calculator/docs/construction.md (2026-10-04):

# Конструктив: дай → блок → объединительная плита

Метрики разбиения считает [`calc/partition.py`](../calc/partition.py), само разбиение лежит в [`model/partition.json`](../model/partition.json).

## Место элемента и дай

Место элемента — **10 × 15 мм**: сам элемент, прямой и инверсный выходы, по два входа управления с каждой стороны, два вентиляционных окна у выходов. Плата — **15 × 10 мест**, массив 150 × 150 мм. По бокам поля по 25 мм под стояки питания, снизу 20 мм под порты, сверху 20 мм: плата ≈ 200 × 190 мм.

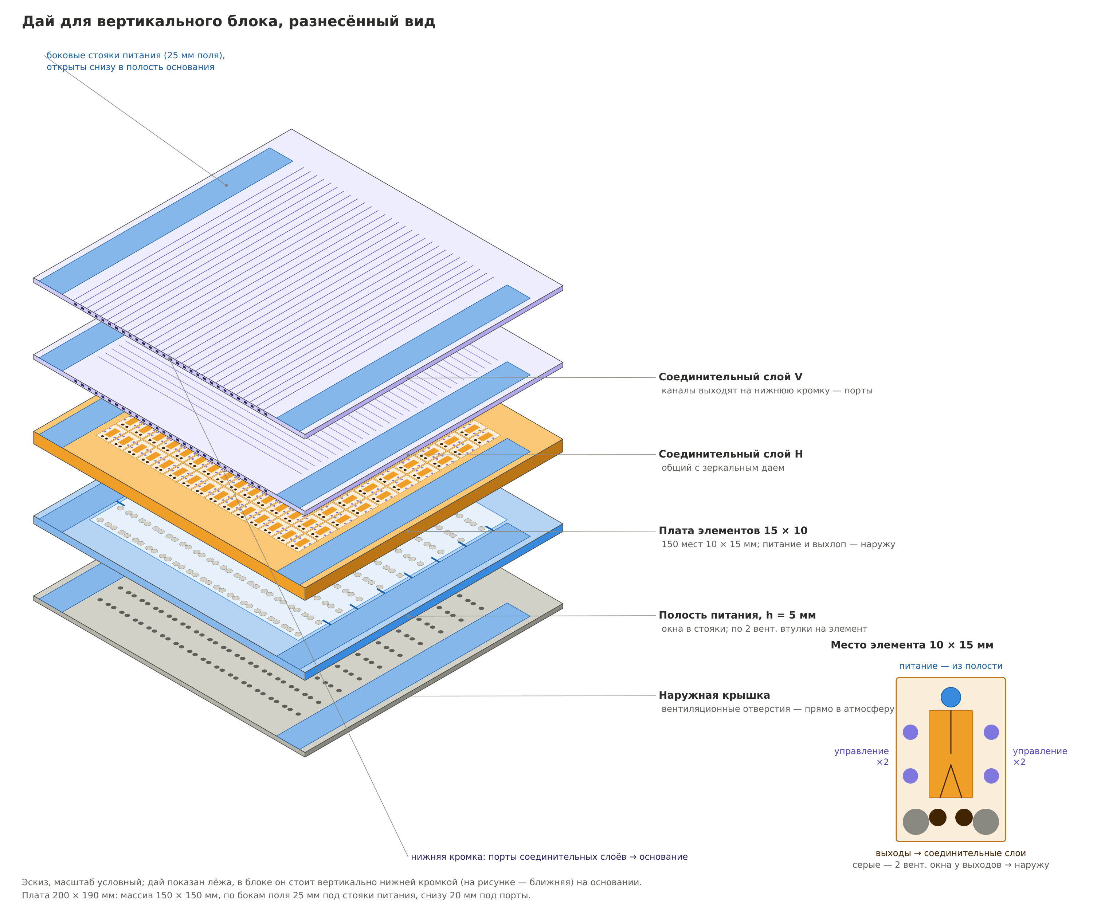
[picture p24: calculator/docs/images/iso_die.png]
Дай в разнесённом виде


| Слой (изнутри наружу) | Толщина | Назначение |
|---|---|---|
| Соединительные слои H / V / H | по ≈ 3 мм | общие с зеркальным даем; каналы выходят на нижнюю кромку |
| Плата элементов | ≈ 8 мм | элементы смотрят внутрь, выходы и управление — в соединительный пакет |
| Полость питания | 5 мм | общая для 150 элементов; окна в боковые стояки; сквозь неё проходят по 2 вентиляционные втулки на элемент |
| Наружная крышка | 3 мм | вентиляционные отверстия прямо в атмосферу |

Отдельный слой выхлопа не нужен: каждое вентиляционное окно выведено своей втулкой сквозь полость питания и крышку наружу.

## Блок: два зеркальных дая

Даи A и B — одна и та же плата, B переворачивается. Между ними общий соединительный пакет, поэтому 300 мест блока соединяются без трубок. Блок в сборе ≈ **41 × 200 × 190 мм** (3 + 5 + 8 + 9 + 8 + 5 + 3) и **стоит вертикально**, как плата в корзине:

- нижняя кромка соединительного пакета с портами ложится на прокладку объединительной плиты — подключение одним прижимом;
- обе наружные стороны блока — крышки с вентиляционными отверстиями, выхлоп уходит в зазоры между блоками;
- в боковых полях проходят вертикальные стояки питания, открытые снизу в буферную полость основания.

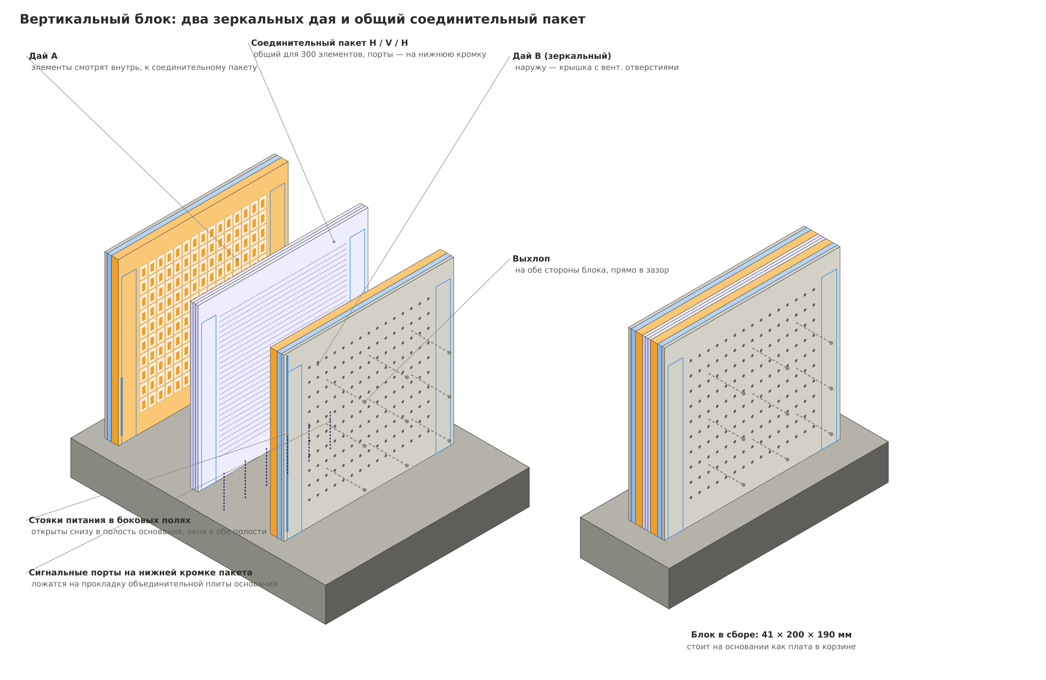
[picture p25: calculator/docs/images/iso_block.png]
Вертикальный блок


## Разбиение схемы

Нетлист разбит по функциям и доработан алгоритмом, который переносит отдельные элементы между платами, если это уменьшает число соединений. Порядок блоков в ряду B1 → B2 → B3 → B4 подобран перебором: данные идут слева направо, от матрицы к табло.

| Блок | Дай A | Дай B | Элементов | Переходов A↔B |
|---|---|---|---|---|
| B1 «Сетчатка» | 19 ключей, нейроны 0–7 (105) | 7 ключей, нейроны 8, 9, + − × = C, шифратор (115) | 220 | 33 |
| B2 «Управление и ввод» | автомат, синхронизатор, Y, OP, знак (90) | регистр X, декремент, генератор фаз (113) | 203 | 16 |
| B3 «АЛУ и результат» | мультиплексор B, дополнение, сумматор (120) | регистр R, маска, инкремент (123) | 243 | 25 |
| B4 «Индикация» | мультиплексор индикации, гашение, дешифраторы ед./дес. (112) | дешифраторы сотен и тысяч (74) | 186 | 2 |

| Соединения между блоками | Линий |
|---|---|
| B1 → B2 | 10 |
| B2 ↔ B3 | 23 + 3 тактовые фазы |
| B3 → B4 | 25 |
| B2 → B4 (мимо B3) | 10 |
| **Всего** | **68 сигнальных + 3 тактовые = 71** |
| для сравнения: 8 отдельных даёв с трубками | 151 |

Тактируются только B2 и B3; B1 и B4 — чистая комбинационная логика.

Портов на нижних кромках: B1 — 36 (в том числе 26 трубочек матрицы), B2 — 40 (в том числе кнопка и знак), B3 — 51, B4 — 63 (в том числе 28 сегментов табло). Ёмкость кромки — около 140 портов (3 слоя пакета, шаг 4 мм).

Буферы разветвления (≈ 95 при нагрузке на выход до 4) в нетлист не вставлены; с ними блоки заполнены на 250–275 мест из 300, запас — на B4 (около 75 мест на дае D8).

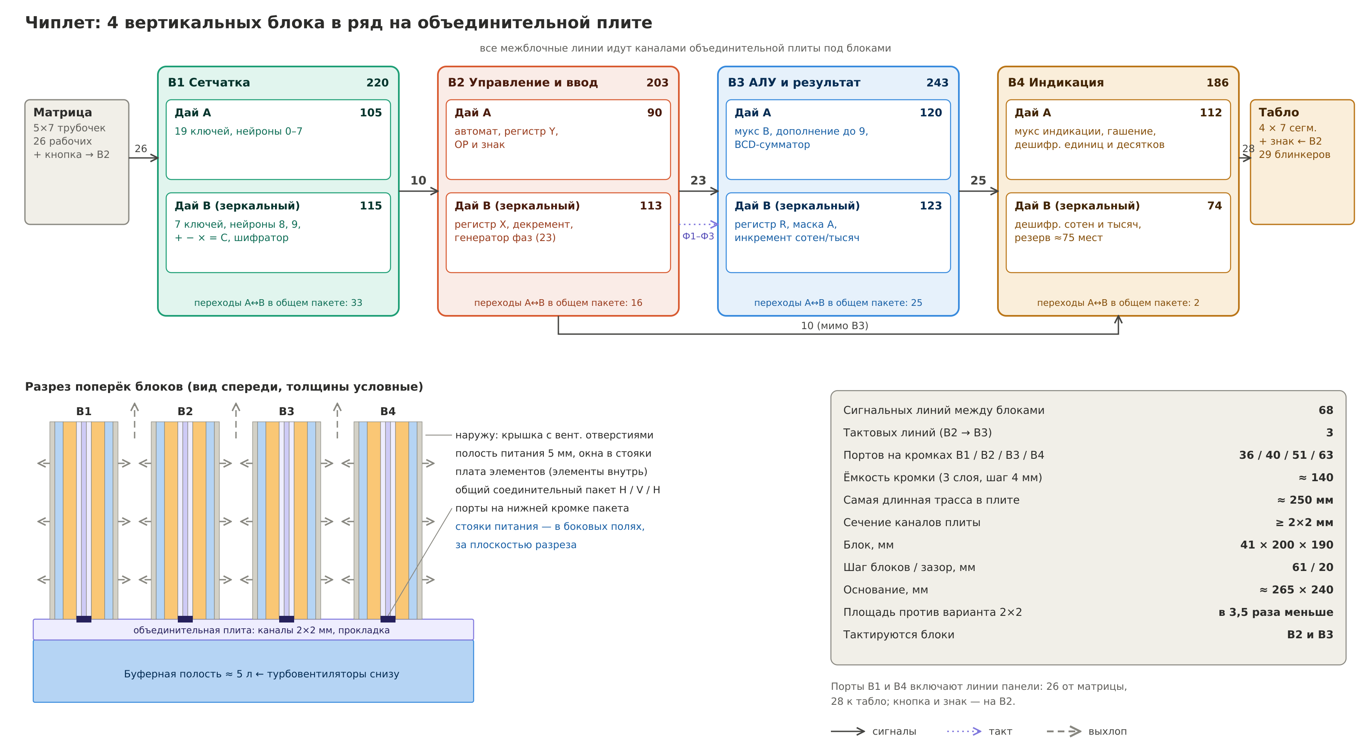
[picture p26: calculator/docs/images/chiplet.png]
Блоки, даи и межблочные линии


## Сборка

| Параметр | Значение |
|---|---|
| Блоки | 4 × (41 × 200 × 190 мм), шаг 61 мм, зазор 20 мм |
| Объединительная плита | ≈ 265 × 240 мм, каналы ≥ 2 × 2 мм в двух слоях |
| Буферная полость под плитой | высота 60–80 мм, ≈ 4–5 л |
| Площадь основания | в 3,5 раза меньше раскладки 2 × 2 (≈ 460 × 480 мм) |

Сборка на объединительной плите

## Объединительная плита

Межблочные линии идут каналами в плите под блоками. Блоки стоят в ряд, поэтому трассы короткие: соседи — шаг 61 мм, самая длинная линия B2 → B4 вместе с подводами ≈ 250 мм.

| Канал, длина 250 мм | Падение давления сигнала при расходе входа управления 0,1 / 0,2 л/мин |
|---|---|
| 1 × 1 мм | 21 / 43 % |
| 1,5 × 1,5 мм | 4,2 / 8,5 % |
| **2 × 2 мм** | **1,3 / 2,7 %** |

Задержка распространения ≈ 1 мс, постоянная RC — доли миллисекунды; на фоне фазы 80–100 мс это ничто. Ограничивает сопротивление канала, поэтому нужны **каналы не меньше 2 × 2 мм**. Расход входа управления (0,1–0,2 л/мин) — допущение, его стоит измерить на реальных элементах.

Механика:

- нижнюю кромку блока фрезеровать в чистовую после склейки — она ложится на прокладку;
- прокладка из силиконового листа 1–2 мм с отверстиями, установочные штифты, прижим сверху планкой на 4 блока;
- 190 портов (134 межблочных + 56 панели) на 4 кромках; каждую линию до сборки опрессовать по спаду давления;
- блок вынимается как плата из корзины; на время снятия порты и окна стояков в плите закрываются заглушкой.

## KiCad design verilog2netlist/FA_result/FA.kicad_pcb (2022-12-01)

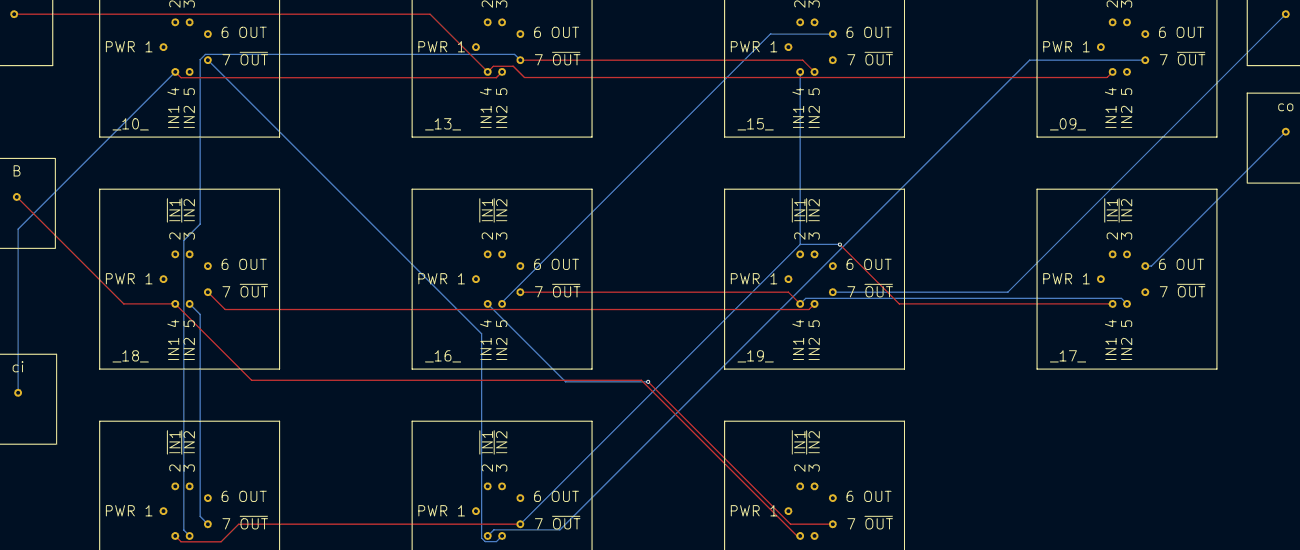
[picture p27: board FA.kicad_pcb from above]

Board: 2 copper layers, 16 parts (0 on the bottom side), 14 nets.

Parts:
A: INPUT
B: INPUT
_09_, _10_, _11_: NOT; NOR
_12_, _13_, _14_, _16_, _18_, _19_: NOR
_15_, _17_: OR; NOR
ci: INPUT
co: OUTPUT
out: OUTPUT

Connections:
A: A.1, _09_.4, _13_.4
B: B.1, _11_.4, _18_.4
_00_: _13_.7, _14_.5, _15_.5
_01_: _14_.7, _18_.5
_02_: _15_.6, _16_.5
_03_: _16_.7, _17_.5, _19_.4
_04_: _18_.7, _19_.5
_05_: _09_.7, _12_.4
_06_: _10_.7, _12_.5
_07_: _11_.7, _16_.4
_08_: _12_.7, _14_.4, _15_.4, _17_.4
ci: _10_.4, _13_.5, ci.1
co: _17_.6, co.1
out: _19_.7, out.1

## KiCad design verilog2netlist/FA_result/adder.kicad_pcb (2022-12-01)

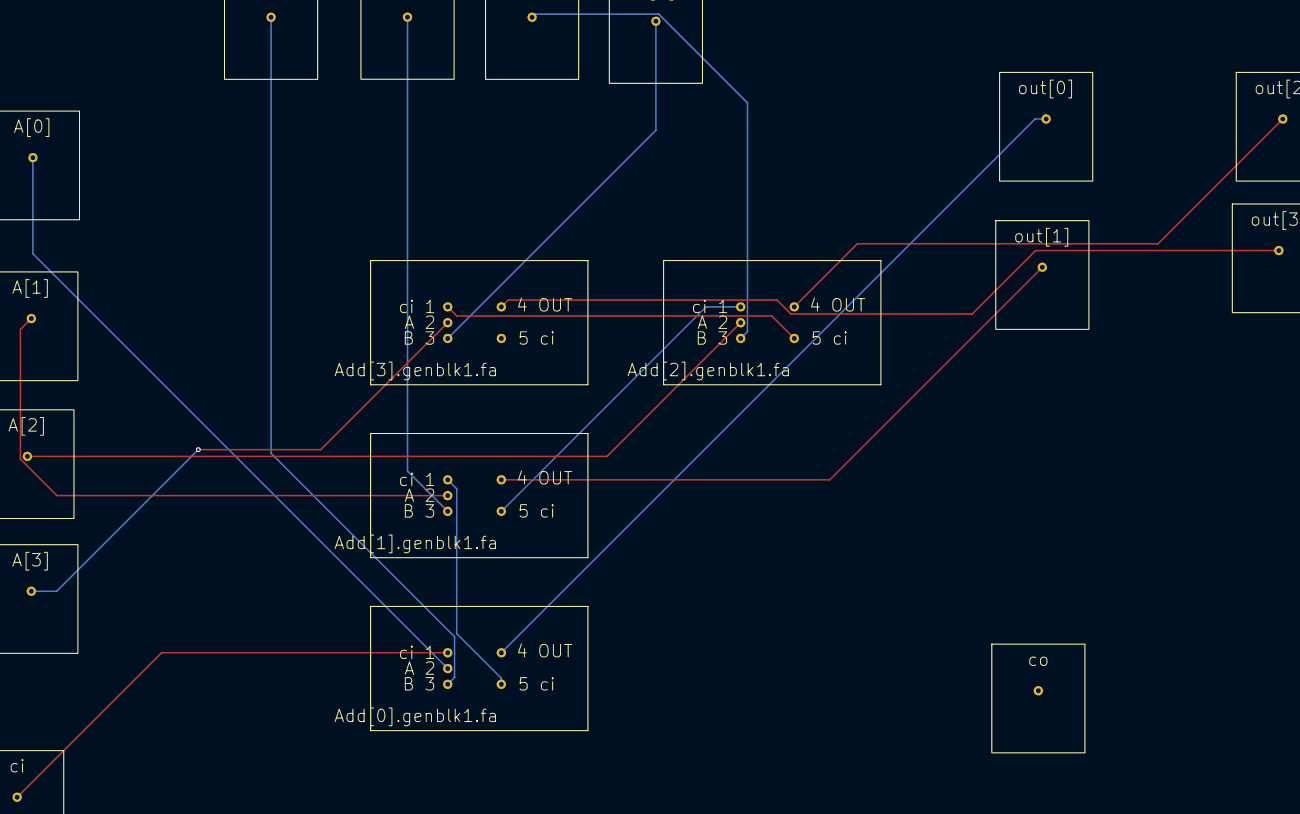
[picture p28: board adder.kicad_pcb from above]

Board: 2 copper layers, 18 parts (0 on the bottom side), 16 nets.

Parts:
A[0], A[1], A[2], A[3]: INPUT
Add[0].genblk1.fa, Add[1].genblk1.fa, Add[2].genblk1.fa, Add[3].genblk1.fa: FA; genblk1.fa
B[0], B[1], B[2], B[3]: INPUT
ci: INPUT
co: OUTPUT
out[0], out[1], out[2], out[3]: OUTPUT

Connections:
A[0]: A[0].1, Add[0].genblk1.fa.2
A[1]: A[1].1, Add[1].genblk1.fa.2
A[2]: A[2].1, Add[2].genblk1.fa.2
A[3]: A[3].1, Add[3].genblk1.fa.2
Add[0].c_out: Add[0].genblk1.fa.5, Add[1].genblk1.fa.1
Add[1].c_out: Add[1].genblk1.fa.5, Add[2].genblk1.fa.1
Add[2].c_out: Add[2].genblk1.fa.5, Add[3].genblk1.fa.1
B[0]: Add[0].genblk1.fa.3, B[0].1
B[1]: Add[1].genblk1.fa.3, B[1].1
B[2]: Add[2].genblk1.fa.3, B[2].1
B[3]: Add[3].genblk1.fa.3, B[3].1
ci: Add[0].genblk1.fa.1, ci.1
out[0]: Add[0].genblk1.fa.4, out[0].1
out[1]: Add[1].genblk1.fa.4, out[1].1
out[2]: Add[2].genblk1.fa.4, out[2].1
out[3]: Add[3].genblk1.fa.4, out[3].1

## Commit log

2022-07-27 add 50u bench
    [Pad_Geometry.stl, patch_1_0.stl, patch_2_0.stl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]
2022-07-27 add kicad sch
    [adder.kicad_pcb, adder.kicad_sch]
2022-08-10 Manual import of 4bit adder to kicad
    [4bit_adder.kicad_sch, FA.kicad_sch, adder.kicad_sch]
2022-10-22 add FreeCAD elements
    [CT41_first.FCStd, CT41_inv.FCStd, Ejector.FCStd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]
2022-12-01 Added verilog2Netlist converter
    This new code conver yosys output to kiCad netlist
    Idea - mine,
    Author - https://habr.com/ru/users/Pechkin1007/
    [FA.kicad_pcb, FA.kicad_sch, adder.kicad_pcb]
2024-11-05 Add VOLGA elements 3d models
    [ST41.FCStd, ST42.FCStd, ST43.FCStd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]
2026-10-04 calculator: модель, нетлист, RTL, CI (черновик для проверки)
    Claude-Session: https://claude.ai/code/session_013TrJRc8KLh2AZumnzUSdJc
2026-10-04 calculator: расчёты, отчёт CI в аннотациях
    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
2026-10-04 calculator: правка тестбенчей и CI
    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
2026-10-04 calculator: README, документация и правила KiCad для даёв
    - корневой README с обзором репозитория и calculator/README.md
    - docs: архитектура, конструктив, питание; схемы картинками (PNG + SVG)
    и скрипты, которые их рисуют
    - verilog2netlist/config.py: правила для даёв калькулятора
    (пока только NOR/OR/NOT на элементе FA:NOR)
    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
